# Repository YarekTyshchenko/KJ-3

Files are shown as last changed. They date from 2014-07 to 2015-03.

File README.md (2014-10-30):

KJ-3
====
Programming ATMega328 using an Arduino Micro
--------------------------------------------

All tutorials around programming ATMegas seem to revolve around removing the MCU from
an Arduino Uno and flashing it using normal methods. Since I don't have an Uno, and I
don't plan on getting one, it doesn't fit my needs, I need something that can go into
a breadboard, i've been having a really hard time collecting all the information on
making it work with a Micro and ISCP

So far i've got a few bits of information:

1. Upload ArduinoISP to your Mega, changing the SS definition to pin 10.
1. Modify boards.txt to include your breadboard configuration, or use Arduino Due 328
1. Add ArduinoISP as Micro definition to programmers.txt, found online somehwere
1. Compile and burn the chip with Shift+Ctrl-U (Shift click upload) to use the programmer...

This results in the code running on your new breadboarded MCU!

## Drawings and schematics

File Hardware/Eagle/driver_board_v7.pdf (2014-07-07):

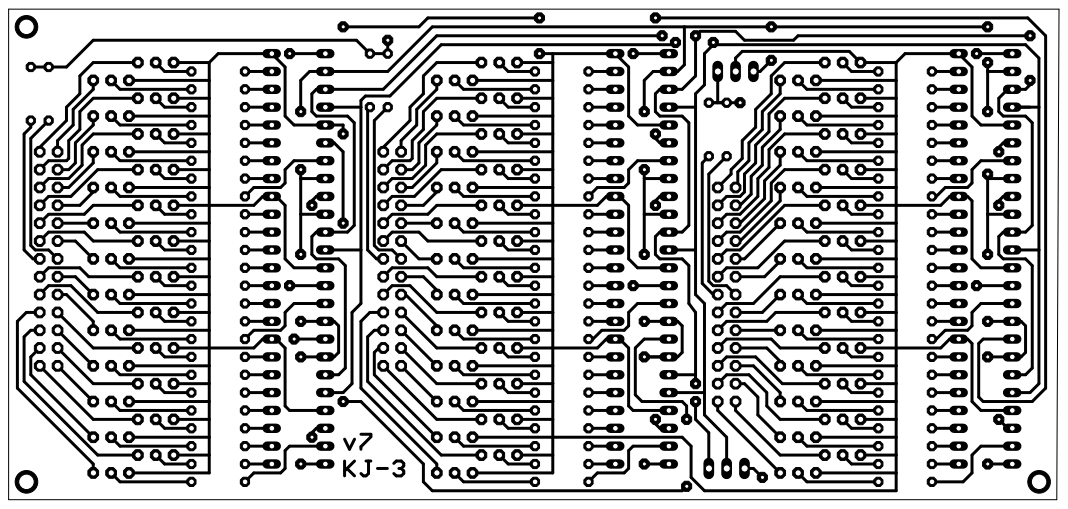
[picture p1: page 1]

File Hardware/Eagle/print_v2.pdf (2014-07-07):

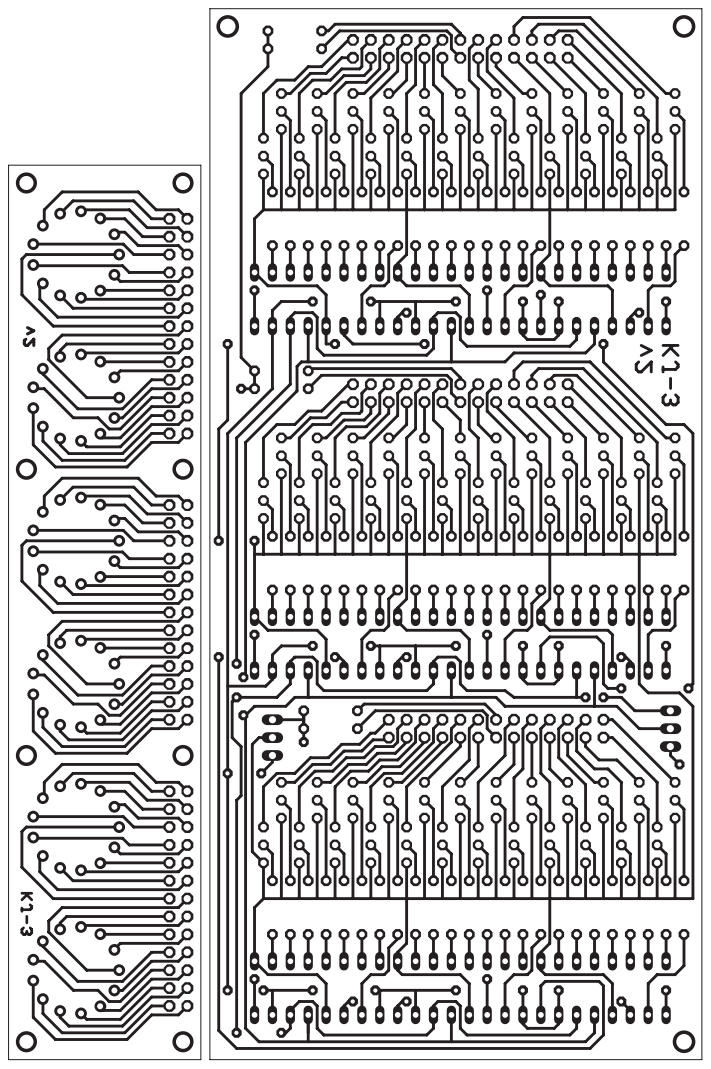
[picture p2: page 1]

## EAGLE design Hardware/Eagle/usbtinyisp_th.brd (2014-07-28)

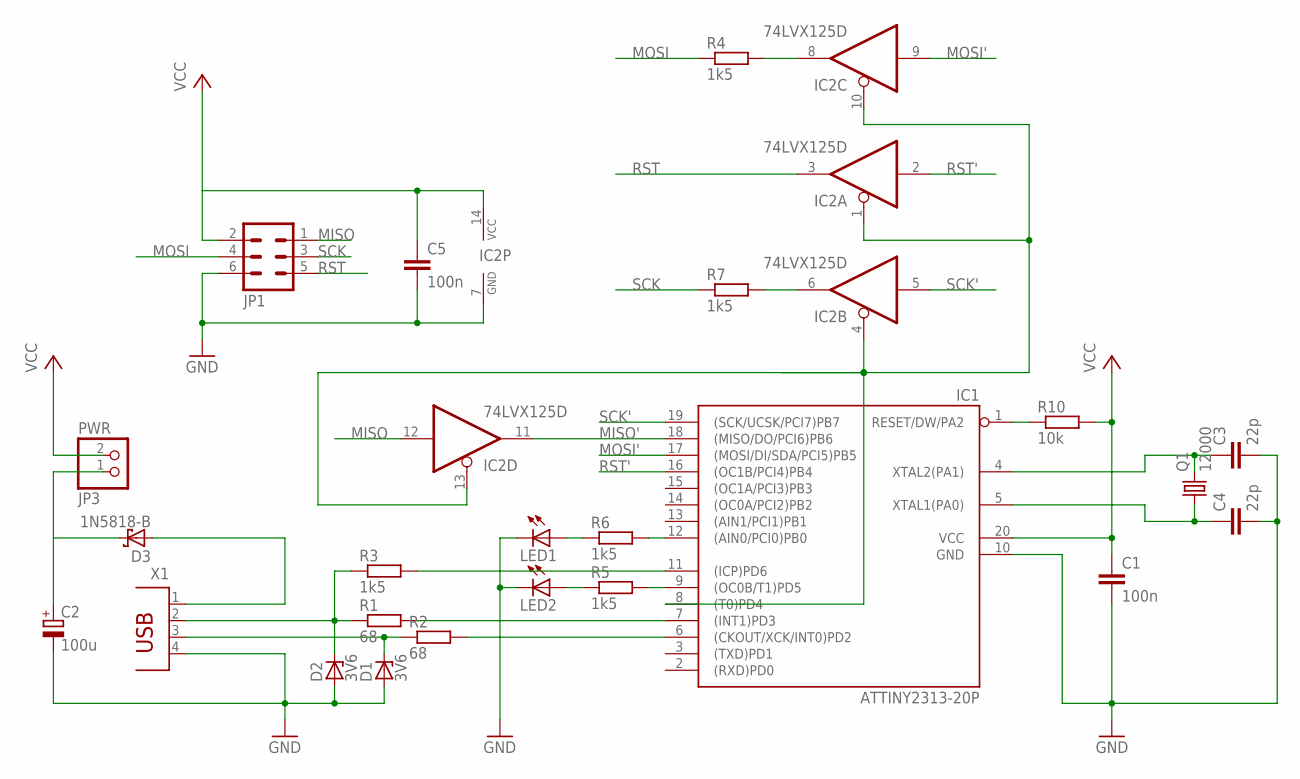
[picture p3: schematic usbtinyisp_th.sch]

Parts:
C1, C5: 100n; C025-025X050
C2: 100u; E2,5-6
C3, C4: 22p; C025-025X050
D1, D2: 3V6; DO35Z10
D3: 1N5818-B; DO41-7.6
IC1: ATTINY2313-20P; DIL20
IC2: 74LVX125D; DIL14
JP1: MA03-2
JP3: PWR; 1X02
LED1, LED2: LED5MM
Q1: 12000; HC49U-V
R1, R2: 68; 0204/7
R3, R4, R5, R6, R7: 1k5; 0204/7
R10: 10k; 0204/7
X1: PN61729

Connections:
GND: C1.2, C2.-, C3.2, C4.2, C5.2, D1.A, D2.A, IC1.10 (GND), IC2.7 (GND), JP1.6, LED1.K (C), LED2.K (C), X1.4
MISO: IC2.12 (I), JP1.1
MISO': IC1.18 ((MISO/DO/PCI6)PB6), IC2.11 (O)
MOSI: JP1.4, R4.1
MOSI': IC1.17 ((MOSI/DI/SDA/PCI5)PB5), IC2.9 (I)
unnamed: D2.C, R1.1, R3.1, X1.2
unnamed: D1.C, R2.1, X1.3
unnamed: IC1.7 ((INT1)PD3), R1.2
unnamed: C2.+, D3.C, JP3.1
unnamed: LED1.A, R6.1
unnamed: IC1.6 ((CKOUT/XCK/INT0)PD2), R2.2
unnamed: IC1.12 ((AIN0/PCI0)PB0), R6.2
unnamed: IC1.1 (RESET/DW/PA2), R10.1
unnamed: IC1.9 ((OC0B/T1)PD5), R5.2
unnamed: LED2.A, R5.1
unnamed: IC2.6 (O), R7.2
unnamed: IC2.8 (O), R4.2
unnamed: IC1.8 ((T0)PD4), IC2.1 (OE), IC2.4 (OE), IC2.10 (OE), IC2.13 (OE)
unnamed: IC1.11 ((ICP)PD6), R3.2
RST: IC2.3 (O), JP1.5
RST': IC1.16 ((OC1B/PCI4)PB4), IC2.2 (I)
SCK: JP1.3, R7.1
SCK': IC1.19 ((SCK/UCSK/PCI7)PB7), IC2.5 (I)
VBUS: D3.A, X1.1
VCC: C1.1, C5.1, IC1.20 (VCC), IC2.14 (VCC), JP1.2, JP3.2, R10.2
XTAL1: C4.1, IC1.5 (XTAL1(PA0)), Q1.1
XTAL2: C3.1, IC1.4 (XTAL2(PA1)), Q1.2

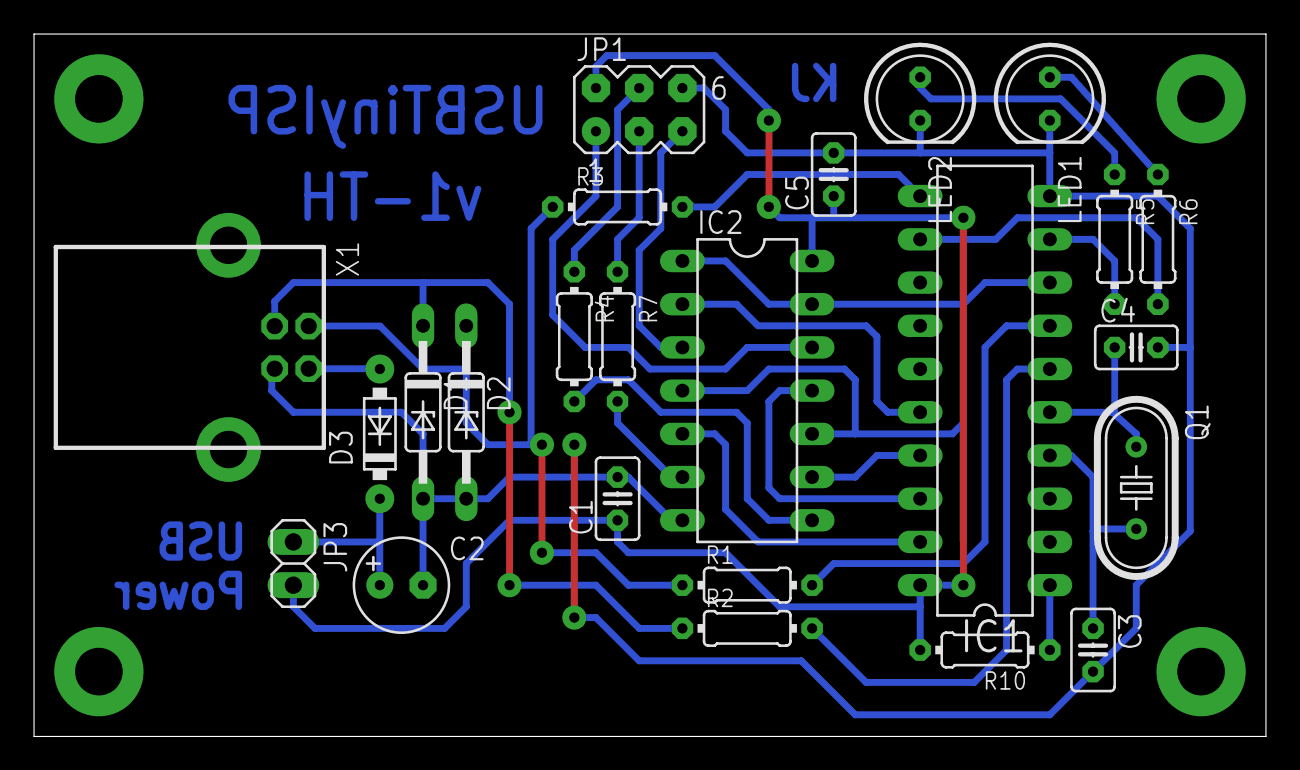
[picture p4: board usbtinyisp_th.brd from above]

Board: 2 copper layers, 72.4 x 41.3 mm, 24 parts (0 on the bottom side), 27 nets.

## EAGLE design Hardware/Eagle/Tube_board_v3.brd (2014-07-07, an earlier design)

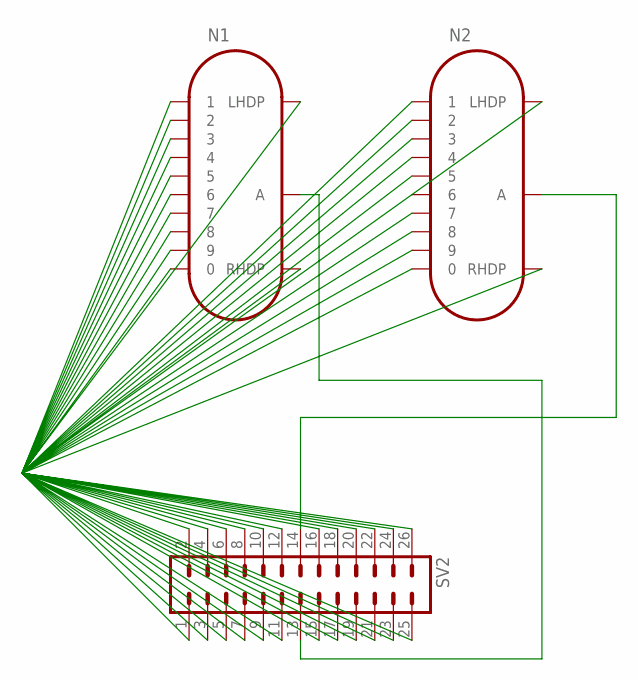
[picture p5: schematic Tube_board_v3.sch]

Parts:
N1, N2: IN-14
SV2: MA13-2

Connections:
unnamed: N1.A, SV2.13
unnamed: N2.A, SV2.14
unnamed: N1.0, N1.1, N1.2, N1.3, N1.4, N1.5, N1.6, N1.7, N1.8, N1.9, N1.LHDP, N1.RHDP, N2.0, N2.1, N2.2, N2.3, N2.4, N2.5, N2.6, N2.7, N2.8, N2.9, N2.LHDP, N2.RHDP, SV2.1, SV2.2, SV2.3, SV2.4, SV2.5, SV2.6, SV2.7, SV2.8, SV2.9, SV2.10, SV2.11, SV2.12, SV2.15, SV2.16, SV2.17, SV2.18, SV2.19, SV2.20, SV2.21, SV2.22, SV2.23, SV2.24, SV2.25, SV2.26

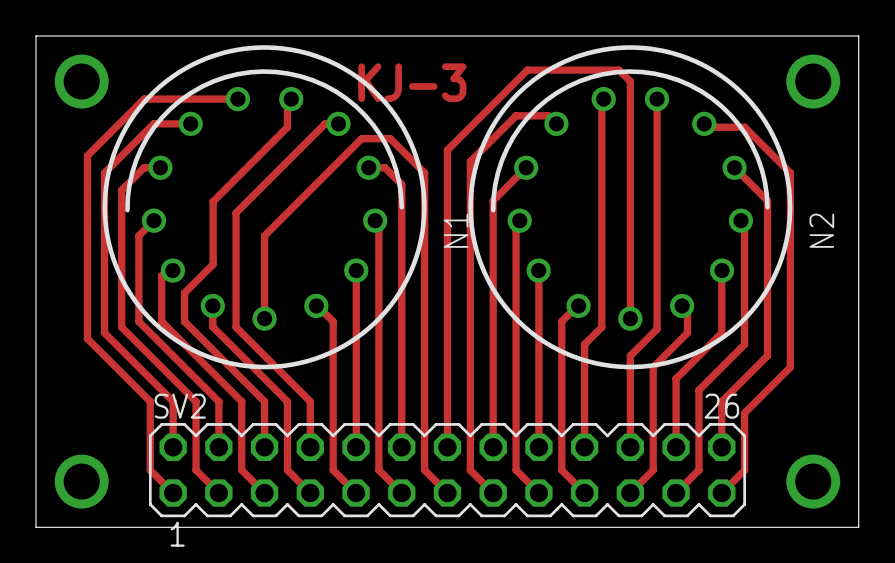
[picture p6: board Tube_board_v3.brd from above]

Board: 2 copper layers, 45.7 x 27.3 mm, 3 parts (0 on the bottom side), 3 nets.

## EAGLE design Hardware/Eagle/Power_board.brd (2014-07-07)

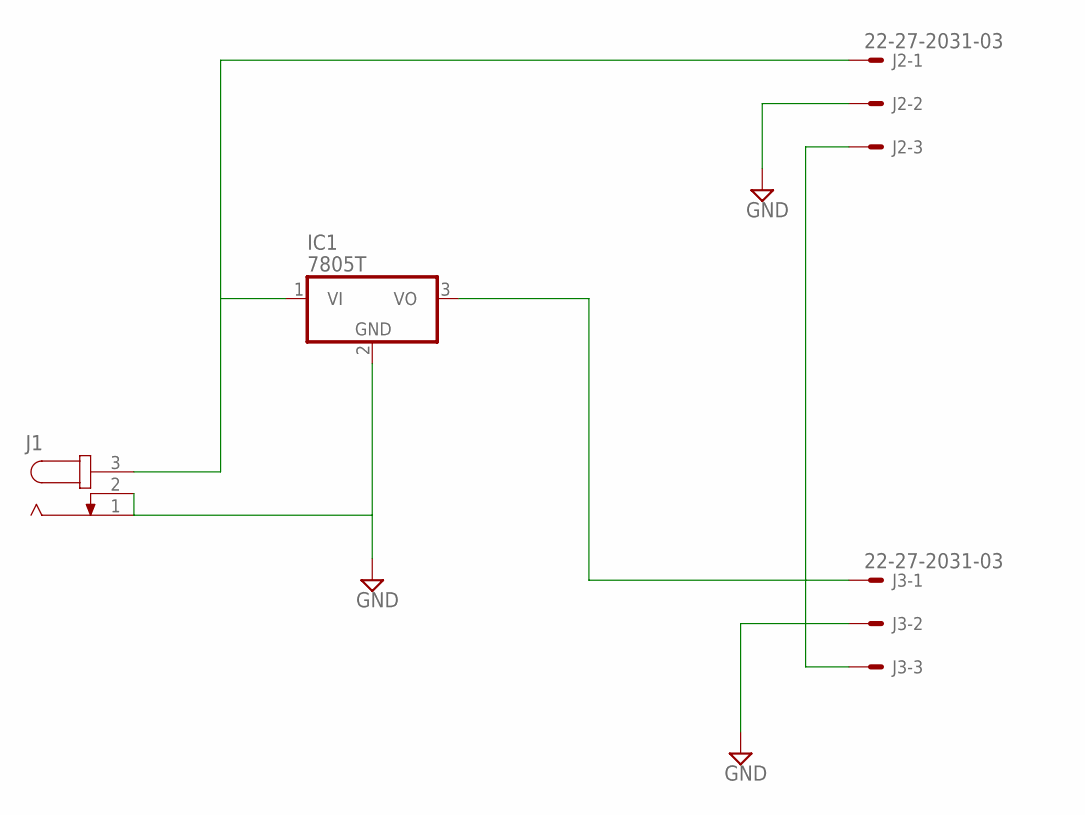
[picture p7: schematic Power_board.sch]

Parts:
IC1: 7805T; TO220H
J1: JACK-PLUG0; SPC4077
J2, J3: 22-27-2031-03; 6410-03

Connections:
GND: IC1.2 (GND), J1.1, J1.2, J2.2, J3.2
unnamed: IC1.1 (VI), J1.3, J2.1
unnamed: J2.3, J3.3
unnamed: IC1.3 (VO), J3.1

Board: 2 copper layers, 4 parts (0 on the bottom side), 4 nets, no tracks yet.

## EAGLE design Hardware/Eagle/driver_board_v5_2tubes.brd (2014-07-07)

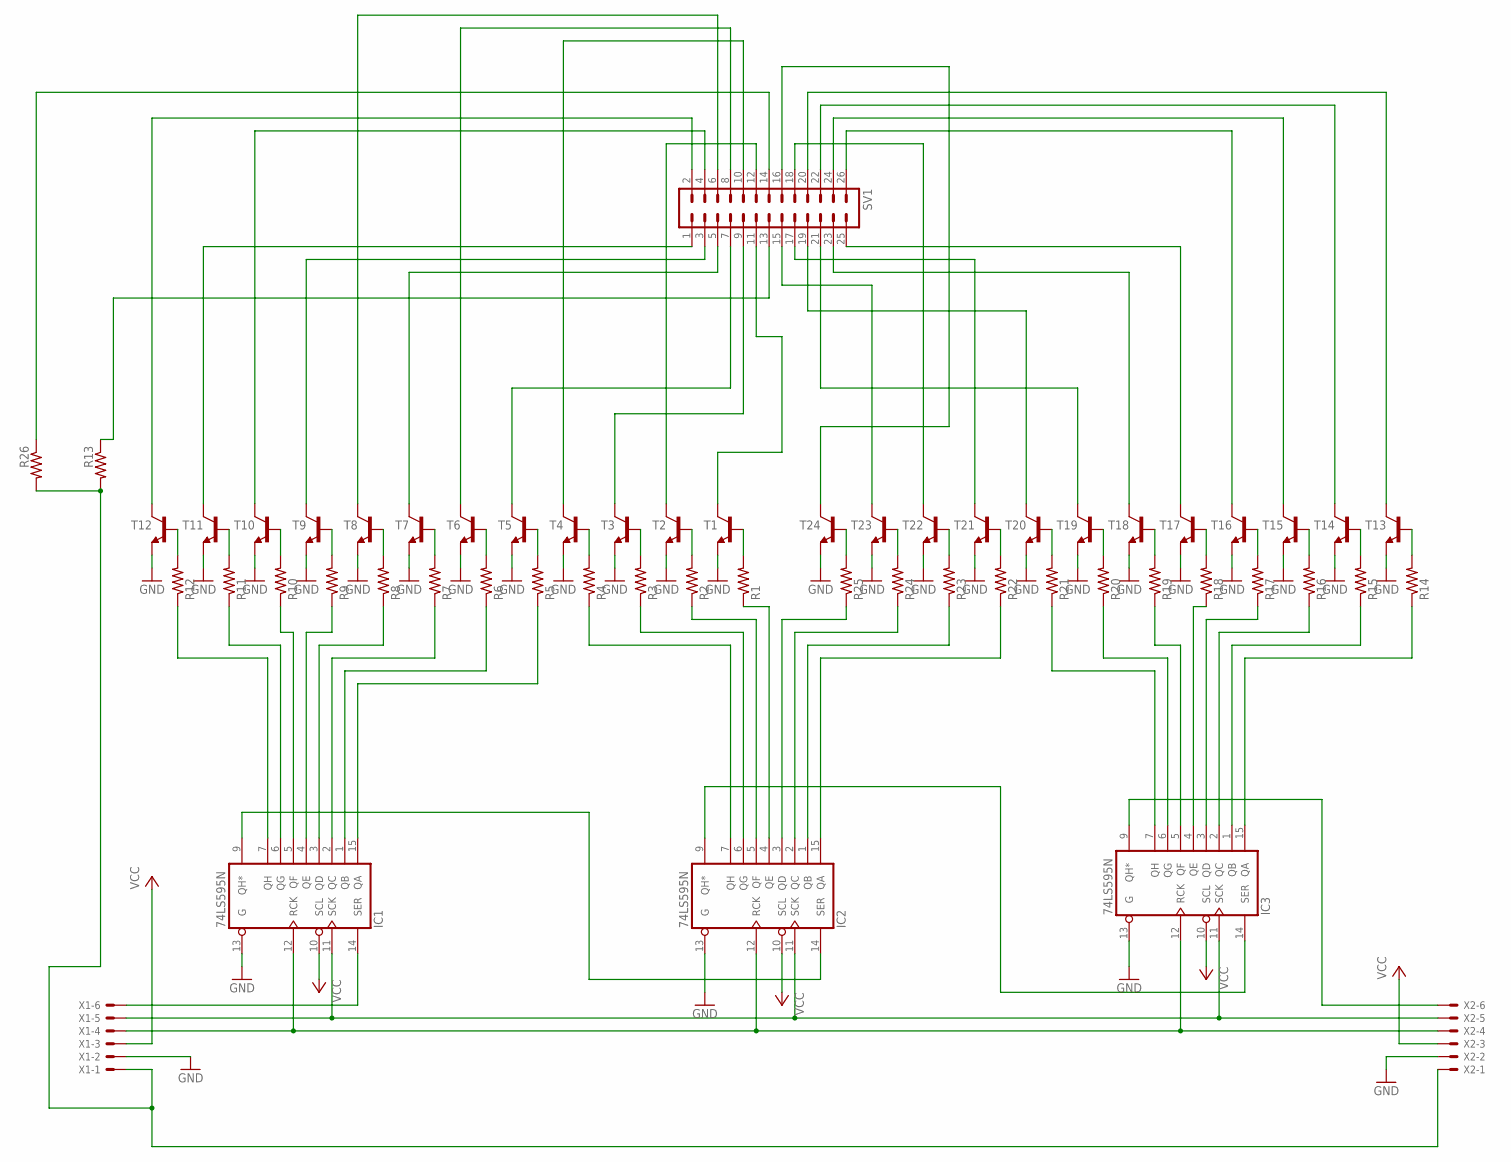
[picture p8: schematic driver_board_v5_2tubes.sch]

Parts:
IC1, IC2, IC3: 74LS595N; DIL16
R1, R2, R3, R4, R5, R6, R7, R8, R9, R10, R11, R12, R13, R14, R15, R16, R17, R18, R19, R20, R21, R22, R23, R24, R25, R26: R-US_0204/7; 0204/7
SV1: MA13-2
T1, T2, T3, T4, T5, T6, T7, T8, T9, T10, T11, T12, T13, T14, T15, T16, T17, T18, T19, T20, T21, T22, T23, T24: 29-NPN-TO92-EBC; TO92-EBC
X1, X2: 22-23-2061

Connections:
GND: IC1.8 (GND), IC1.13 (G), IC2.8 (GND), IC2.13 (G), IC3.8 (GND), IC3.13 (G), T1.E, T2.E, T3.E, T4.E, T5.E, T6.E, T7.E, T8.E, T9.E, T10.E, T11.E, T12.E, T13.E, T14.E, T15.E, T16.E, T17.E, T18.E, T19.E, T20.E, T21.E, T22.E, T23.E, T24.E, X1.2, X2.2
unnamed: R12.2, T12.B
unnamed: R11.2, T11.B
unnamed: R10.2, T10.B
unnamed: R9.2, T9.B
unnamed: R8.2, T8.B
unnamed: R7.2, T7.B
unnamed: R6.2, T6.B
unnamed: R5.2, T5.B
unnamed: R4.2, T4.B
unnamed: R3.2, T3.B
unnamed: R2.2, T2.B
unnamed: R1.2, T1.B
unnamed: SV1.11, T1.C
unnamed: SV1.3, T9.C
unnamed: SV1.6, T8.C
unnamed: SV1.5, T7.C
unnamed: SV1.12, T2.C
unnamed: SV1.9, T3.C
unnamed: SV1.8, T6.C
unnamed: SV1.7, T5.C
unnamed: SV1.10, T4.C
unnamed: R26.1, SV1.14
unnamed: R25.2, T24.B
unnamed: R24.2, T23.B
unnamed: R23.2, T22.B
unnamed: R22.2, T21.B
unnamed: R21.2, T20.B
unnamed: R20.2, T19.B
unnamed: R19.2, T18.B
unnamed: R18.2, T17.B
unnamed: R17.2, T16.B
unnamed: R16.2, T15.B
unnamed: R15.2, T14.B
unnamed: R14.2, T13.B
unnamed: SV1.16, T24.C
unnamed: SV1.15, T23.C
unnamed: SV1.18, T22.C
unnamed: SV1.17, T21.C
unnamed: SV1.19, T20.C
unnamed: SV1.21, T19.C
unnamed: SV1.20, T13.C
unnamed: SV1.22, T14.C
unnamed: SV1.24, T15.C
unnamed: SV1.23, T18.C
unnamed: SV1.25, T17.C
unnamed: SV1.26, T16.C
unnamed: R13.2, R26.2, X1.1, X2.1
unnamed: R13.1, SV1.13
unnamed: IC1.9 (QH*), IC2.14 (SER)
unnamed: IC2.9 (QH*), IC3.14 (SER)
unnamed: IC3.9 (QH*), X2.6
unnamed: IC1.14 (SER), X1.6
unnamed: SV1.2, T12.C
unnamed: IC1.11 (SCK), IC2.11 (SCK), IC3.11 (SCK), X1.5, X2.5
unnamed: IC1.12 (RCK), IC2.12 (RCK), IC3.12 (RCK), X1.4, X2.4
unnamed: SV1.1, T11.C
unnamed: SV1.4, T10.C
unnamed: IC1.7 (QH), R12.1
unnamed: IC1.6 (QG), R11.1
unnamed: IC1.5 (QF), R10.1
unnamed: IC1.4 (QE), R9.1
unnamed: IC1.3 (QD), R8.1
unnamed: IC1.2 (QC), R7.1
unnamed: IC1.1 (QB), R6.1
unnamed: IC1.15 (QA), R5.1
unnamed: IC2.7 (QH), R4.1
unnamed: IC2.6 (QG), R3.1
unnamed: IC2.5 (QF), R2.1
unnamed: IC2.4 (QE), R1.1
unnamed: IC2.3 (QD), R25.1
unnamed: IC2.2 (QC), R24.1
unnamed: IC2.1 (QB), R23.1
unnamed: IC2.15 (QA), R22.1
unnamed: IC3.7 (QH), R21.1
unnamed: IC3.6 (QG), R20.1
unnamed: IC3.5 (QF), R19.1
unnamed: IC3.4 (QE), R18.1
unnamed: IC3.3 (QD), R17.1
unnamed: IC3.2 (QC), R16.1
unnamed: IC3.1 (QB), R15.1
unnamed: IC3.15 (QA), R14.1
VCC: IC1.10 (SCL), IC1.16 (VCC), IC2.10 (SCL), IC2.16 (VCC), IC3.10 (SCL), IC3.16 (VCC), X1.3, X2.3

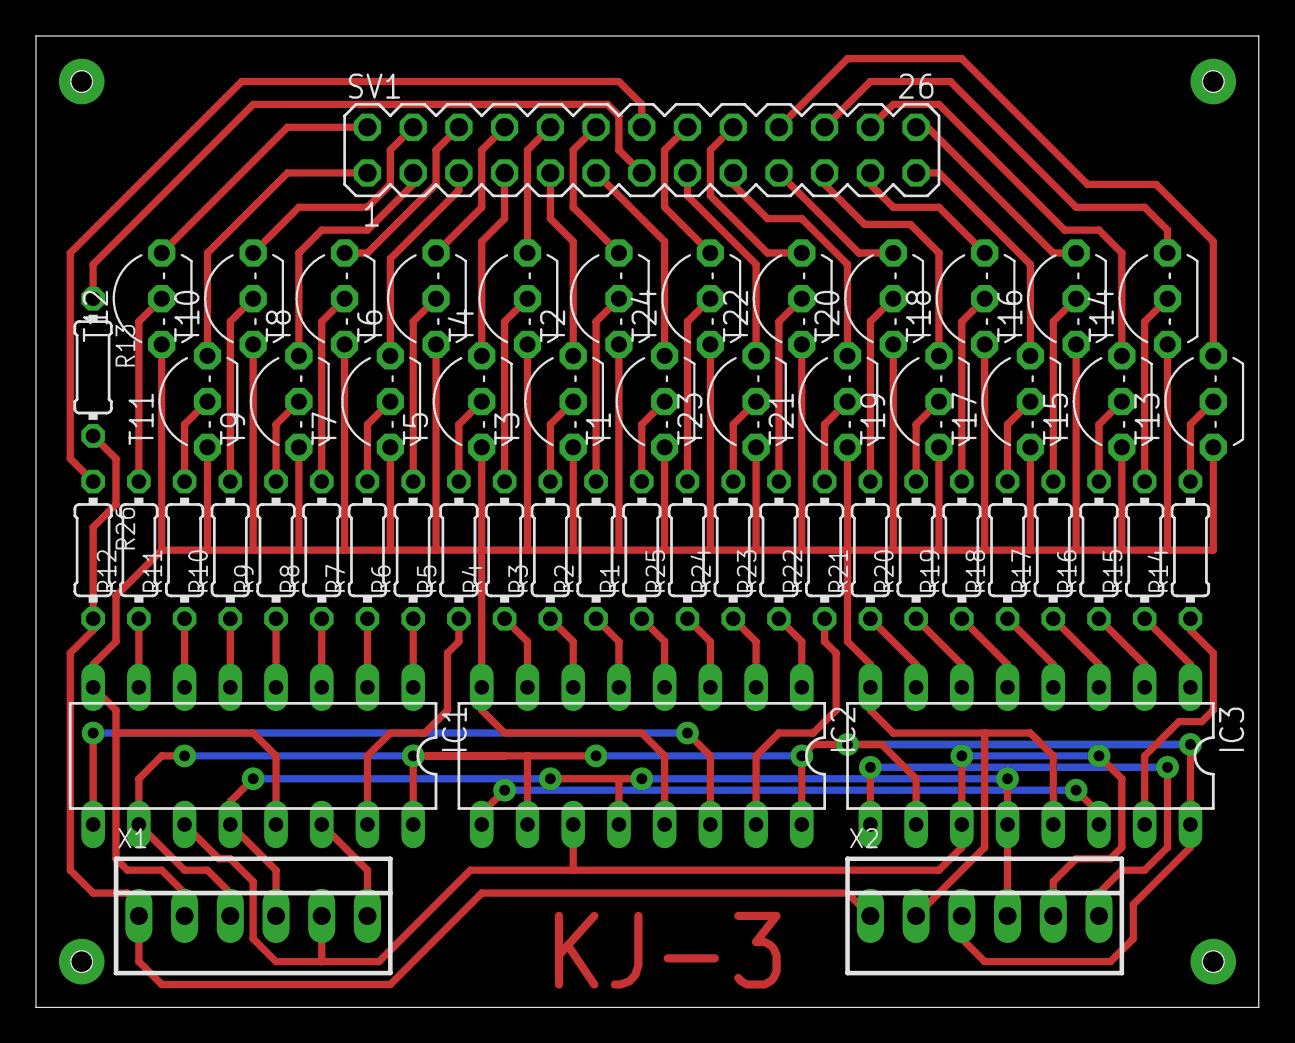
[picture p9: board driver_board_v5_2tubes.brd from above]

Board: 2 copper layers, 67.9 x 54.0 mm, 56 parts (0 on the bottom side), 83 nets.

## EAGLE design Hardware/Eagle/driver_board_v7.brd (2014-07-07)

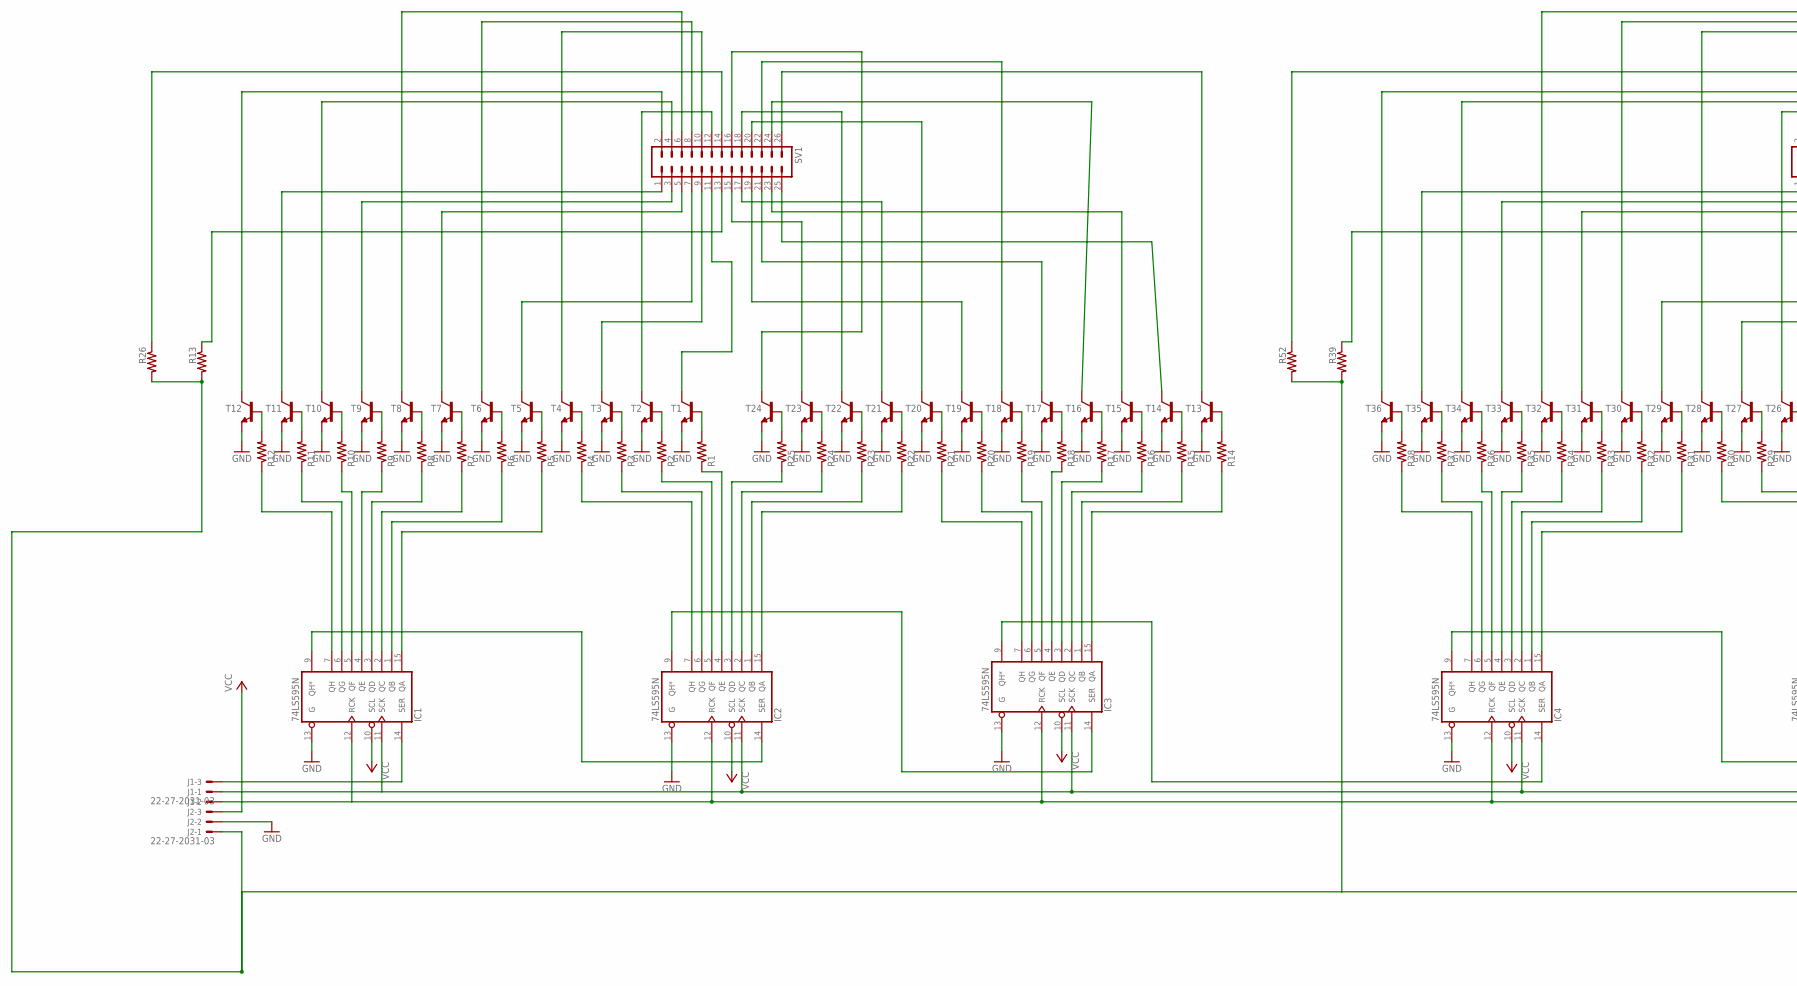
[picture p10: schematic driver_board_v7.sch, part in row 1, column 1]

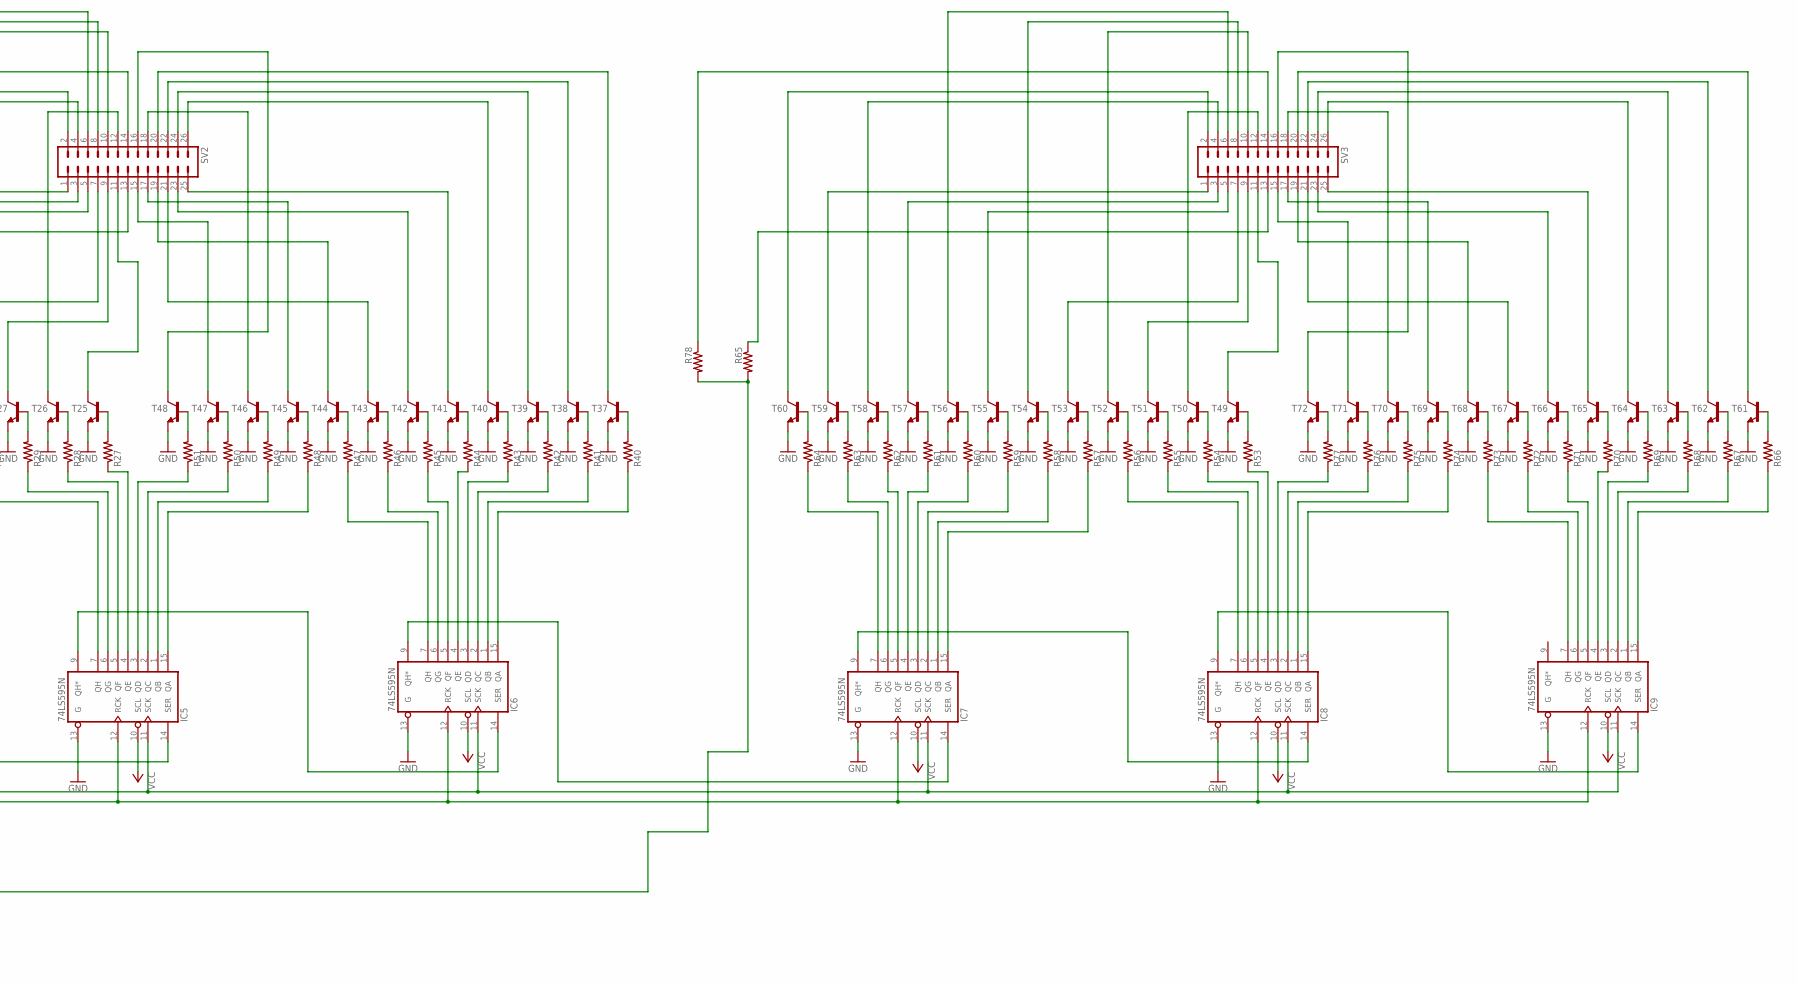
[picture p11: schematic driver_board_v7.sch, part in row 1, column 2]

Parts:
IC1, IC2, IC3, IC4, IC5, IC6, IC7, IC8, IC9: 74LS595N; DIL16
J1, J2: 22-27-2031-03; 6410-03
R1, R2, R3, R4, R5, R6, R7, R8, R9, R10, R11, R12, R13, R14, R15, R16, R17, R18, R19, R20, R21, R22, R23, R24, R25, R26, R27, R28, R29, R30, R31, R32, R33, R34, R35, R36, R37, R38, R39, R40, R41, R42, R43, R44, R45, R46, R47, R48, R49, R50, R51, R52, R53, R54, R55, R56, R57, R58, R59, R60, R61, R62, R63, R64, R65, R66, R67, R68, R69, R70, R71, R72, R73, R74, R75, R76, R77, R78: R-US_0204/7; 0204/7
SV1, SV2, SV3: MA13-2
T1, T2, T3, T4, T5, T6, T7, T8, T9, T10, T11, T12, T13, T14, T15, T16, T17, T18, T19, T20, T21, T22, T23, T24, T25, T26, T27, T28, T29, T30, T31, T32, T33, T34, T35, T36, T37, T38, T39, T40, T41, T42, T43, T44, T45, T46, T47, T48, T49, T50, T51, T52, T53, T54, T55, T56, T57, T58, T59, T60, T61, T62, T63, T64, T65, T66, T67, T68, T69, T70, T71, T72: 29-NPN-TO92-EBC; TO92-EBC

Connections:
GND: IC1.8 (GND), IC1.13 (G), IC2.8 (GND), IC2.13 (G), IC3.8 (GND), IC3.13 (G), IC4.8 (GND), IC4.13 (G), IC5.8 (GND), IC5.13 (G), IC6.8 (GND), IC6.13 (G), IC7.8 (GND), IC7.13 (G), IC8.8 (GND), IC8.13 (G), IC9.8 (GND), IC9.13 (G), J2.2, T1.E, T2.E, T3.E, T4.E, T5.E, T6.E, T7.E, T8.E, T9.E, T10.E, T11.E, T12.E, T13.E, T14.E, T15.E, T16.E, T17.E, T18.E, T19.E, T20.E, T21.E, T22.E, T23.E, T24.E, T25.E, T26.E, T27.E, T28.E, T29.E, T30.E, T31.E, T32.E, T33.E, T34.E, T35.E, T36.E, T37.E, T38.E, T39.E, T40.E, T41.E, T42.E, T43.E, T44.E, T45.E, T46.E, T47.E, T48.E, T49.E, T50.E, T51.E, T52.E, T53.E, T54.E, T55.E, T56.E, T57.E, T58.E, T59.E, T60.E, T61.E, T62.E, T63.E, T64.E, T65.E, T66.E, T67.E, T68.E, T69.E, T70.E, T71.E, T72.E
HV: J2.1, R13.2, R26.2, R39.2, R52.2, R65.2, R78.2
unnamed: R12.2, T12.B
unnamed: R11.2, T11.B
unnamed: R10.2, T10.B
unnamed: R9.2, T9.B
unnamed: R8.2, T8.B
unnamed: R7.2, T7.B
unnamed: R6.2, T6.B
unnamed: R5.2, T5.B
unnamed: R4.2, T4.B
unnamed: R3.2, T3.B
unnamed: R2.2, T2.B
unnamed: R1.2, T1.B
unnamed: SV1.11, T1.C
unnamed: R38.2, T36.B
unnamed: R37.2, T35.B
unnamed: SV1.3, T9.C
unnamed: SV1.6, T8.C
unnamed: SV1.5, T7.C
unnamed: R36.2, T34.B
unnamed: SV1.12, T2.C
unnamed: SV1.9, T3.C
unnamed: SV1.8, T6.C
unnamed: SV1.7, T5.C
unnamed: SV1.10, T4.C
unnamed: R26.1, SV1.14
unnamed: R25.2, T24.B
unnamed: R24.2, T23.B
unnamed: R23.2, T22.B
unnamed: R22.2, T21.B
unnamed: R21.2, T20.B
unnamed: R20.2, T19.B
unnamed: R19.2, T18.B
unnamed: R18.2, T17.B
unnamed: R17.2, T16.B
unnamed: R16.2, T15.B
unnamed: R15.2, T14.B
unnamed: R14.2, T13.B
unnamed: SV1.16, T24.C
unnamed: SV1.15, T23.C
unnamed: SV1.18, T22.C
unnamed: SV1.17, T21.C
unnamed: SV1.20, T20.C
unnamed: SV1.19, T19.C
unnamed: SV1.26, T13.C
unnamed: SV1.25, T14.C
unnamed: SV1.23, T15.C
unnamed: SV1.22, T18.C
unnamed: SV1.21, T17.C
unnamed: SV1.24, T16.C
unnamed: R13.1, SV1.13
unnamed: IC1.9 (QH*), IC2.14 (SER)
unnamed: IC2.9 (QH*), IC3.14 (SER)
unnamed: IC3.9 (QH*), IC4.14 (SER)
unnamed: R35.2, T33.B
unnamed: SV1.2, T12.C
unnamed: SV1.1, T11.C
unnamed: SV1.4, T10.C
unnamed: R34.2, T32.B
unnamed: R33.2, T31.B
unnamed: R32.2, T30.B
unnamed: R31.2, T29.B
unnamed: R30.2, T28.B
unnamed: R29.2, T27.B
unnamed: R28.2, T26.B
unnamed: R27.2, T25.B
unnamed: SV2.3, T33.C
unnamed: SV2.6, T32.C
unnamed: SV2.5, T31.C
unnamed: SV2.12, T26.C
unnamed: SV2.9, T27.C
unnamed: IC1.7 (QH), R12.1
unnamed: IC1.6 (QG), R11.1
unnamed: IC1.5 (QF), R10.1
unnamed: IC1.4 (QE), R9.1
unnamed: IC1.3 (QD), R8.1
unnamed: IC1.2 (QC), R7.1
unnamed: IC1.1 (QB), R6.1
unnamed: IC1.15 (QA), R5.1
unnamed: SV2.8, T30.C
unnamed: IC2.7 (QH), R4.1
unnamed: IC2.6 (QG), R3.1
unnamed: IC2.5 (QF), R2.1
unnamed: IC2.4 (QE), R1.1
unnamed: IC2.3 (QD), R25.1
unnamed: IC2.2 (QC), R24.1
unnamed: IC2.1 (QB), R23.1
unnamed: IC2.15 (QA), R22.1
unnamed: IC3.7 (QH), R21.1
unnamed: IC3.6 (QG), R20.1
unnamed: IC3.5 (QF), R19.1
unnamed: IC3.4 (QE), R18.1
unnamed: IC3.3 (QD), R17.1
unnamed: IC3.2 (QC), R16.1
unnamed: IC3.1 (QB), R15.1
unnamed: IC3.15 (QA), R14.1
unnamed: SV2.7, T29.C
unnamed: SV2.10, T28.C
unnamed: R51.2, T48.B
unnamed: R50.2, T47.B
unnamed: R49.2, T46.B
unnamed: R48.2, T45.B
unnamed: R47.2, T44.B
unnamed: R46.2, T43.B
unnamed: R45.2, T42.B
unnamed: R44.2, T41.B
unnamed: R43.2, T40.B
unnamed: R42.2, T39.B
unnamed: R41.2, T38.B
unnamed: R40.2, T37.B
unnamed: SV2.16, T48.C
unnamed: SV2.15, T47.C
unnamed: SV2.18, T46.C
unnamed: SV2.17, T45.C
unnamed: SV2.19, T44.C
unnamed: SV2.21, T43.C
unnamed: SV2.20, T37.C
unnamed: SV2.22, T38.C
unnamed: SV2.24, T39.C
unnamed: SV2.23, T42.C
unnamed: SV2.25, T41.C
unnamed: SV2.26, T40.C
unnamed: IC4.7 (QH), R38.1
unnamed: IC4.6 (QG), R37.1
unnamed: IC4.5 (QF), R36.1
unnamed: IC4.4 (QE), R35.1
unnamed: IC4.3 (QD), R34.1
unnamed: IC4.2 (QC), R33.1
unnamed: IC4.1 (QB), R32.1
unnamed: IC4.15 (QA), R31.1
unnamed: IC5.7 (QH), R30.1
unnamed: IC5.6 (QG), R29.1
unnamed: IC5.5 (QF), R28.1
unnamed: IC5.4 (QE), R27.1
unnamed: IC5.3 (QD), R51.1
unnamed: IC5.2 (QC), R50.1
unnamed: IC5.1 (QB), R49.1
unnamed: IC5.15 (QA), R48.1
unnamed: IC6.7 (QH), R47.1
unnamed: IC6.6 (QG), R46.1
unnamed: IC6.5 (QF), R45.1
unnamed: IC6.4 (QE), R44.1
unnamed: IC6.3 (QD), R43.1
unnamed: IC6.2 (QC), R42.1
unnamed: IC6.1 (QB), R41.1
unnamed: IC6.15 (QA), R40.1
unnamed: IC4.9 (QH*), IC5.14 (SER)
unnamed: IC5.9 (QH*), IC6.14 (SER)
unnamed: IC6.9 (QH*), IC7.14 (SER)
unnamed: SV2.11, T25.C
unnamed: R52.1, SV2.14
unnamed: R39.1, SV2.13
unnamed: SV2.2, T36.C
unnamed: SV2.1, T35.C
unnamed: SV2.4, T34.C
unnamed: R64.2, T60.B
unnamed: R63.2, T59.B
unnamed: R62.2, T58.B
unnamed: R61.2, T57.B
unnamed: R60.2, T56.B
unnamed: R59.2, T55.B
unnamed: R58.2, T54.B
unnamed: R57.2, T53.B
unnamed: R56.2, T52.B
unnamed: R55.2, T51.B
unnamed: R54.2, T50.B
unnamed: R53.2, T49.B
unnamed: SV3.3, T57.C
unnamed: SV3.6, T56.C
unnamed: SV3.5, T55.C
unnamed: SV3.12, T50.C
unnamed: SV3.9, T51.C
unnamed: SV3.8, T54.C
unnamed: SV3.7, T53.C
unnamed: SV3.10, T52.C
unnamed: R77.2, T72.B
unnamed: R76.2, T71.B
unnamed: R75.2, T70.B
unnamed: R74.2, T69.B
unnamed: R73.2, T68.B
unnamed: R72.2, T67.B
unnamed: R71.2, T66.B
unnamed: R70.2, T65.B
unnamed: R69.2, T64.B
unnamed: R68.2, T63.B
unnamed: R67.2, T62.B
unnamed: R66.2, T61.B
unnamed: SV3.16, T72.C
unnamed: SV3.15, T71.C
unnamed: SV3.18, T70.C
unnamed: SV3.17, T69.C
unnamed: SV3.19, T68.C
unnamed: SV3.21, T67.C
unnamed: SV3.20, T61.C
unnamed: SV3.22, T62.C
unnamed: SV3.24, T63.C
unnamed: SV3.23, T66.C
unnamed: SV3.25, T65.C
unnamed: SV3.26, T64.C
unnamed: IC7.7 (QH), R64.1
unnamed: IC7.6 (QG), R63.1
unnamed: IC7.5 (QF), R62.1
unnamed: IC7.4 (QE), R61.1
unnamed: IC7.3 (QD), R60.1
unnamed: IC7.2 (QC), R59.1
unnamed: IC7.1 (QB), R58.1
unnamed: IC7.15 (QA), R57.1
unnamed: IC8.7 (QH), R56.1
unnamed: IC8.6 (QG), R55.1
unnamed: IC8.5 (QF), R54.1
unnamed: IC8.4 (QE), R53.1
unnamed: IC8.3 (QD), R77.1
unnamed: IC8.2 (QC), R76.1
unnamed: IC8.1 (QB), R75.1
unnamed: IC8.15 (QA), R74.1
unnamed: IC9.7 (QH), R73.1
unnamed: IC9.6 (QG), R72.1
unnamed: IC9.5 (QF), R71.1
unnamed: IC9.4 (QE), R70.1
unnamed: IC9.3 (QD), R69.1
unnamed: IC9.2 (QC), R68.1
unnamed: IC9.1 (QB), R67.1
unnamed: IC9.15 (QA), R66.1
unnamed: IC7.9 (QH*), IC8.14 (SER)
unnamed: IC8.9 (QH*), IC9.14 (SER)
unnamed: SV3.11, T49.C
unnamed: R78.1, SV3.14
unnamed: R65.1, SV3.13
unnamed: SV3.2, T60.C
unnamed: SV3.1, T59.C
unnamed: SV3.4, T58.C
RCK: IC1.12 (RCK), IC2.12 (RCK), IC3.12 (RCK), IC4.12 (RCK), IC5.12 (RCK), IC6.12 (RCK), IC7.12 (RCK), IC8.12 (RCK), IC9.12 (RCK), J1.2
SCK: IC1.11 (SCK), IC2.11 (SCK), IC3.11 (SCK), IC4.11 (SCK), IC5.11 (SCK), IC6.11 (SCK), IC7.11 (SCK), IC8.11 (SCK), IC9.11 (SCK), J1.1
SER: IC1.14 (SER), J1.3
VCC: IC1.10 (SCL), IC1.16 (VCC), IC2.10 (SCL), IC2.16 (VCC), IC3.10 (SCL), IC3.16 (VCC), IC4.10 (SCL), IC4.16 (VCC), IC5.10 (SCL), IC5.16 (VCC), IC6.10 (SCL), IC6.16 (VCC), IC7.10 (SCL), IC7.16 (VCC), IC8.10 (SCL), IC8.16 (VCC), IC9.10 (SCL), IC9.16 (VCC), J2.3

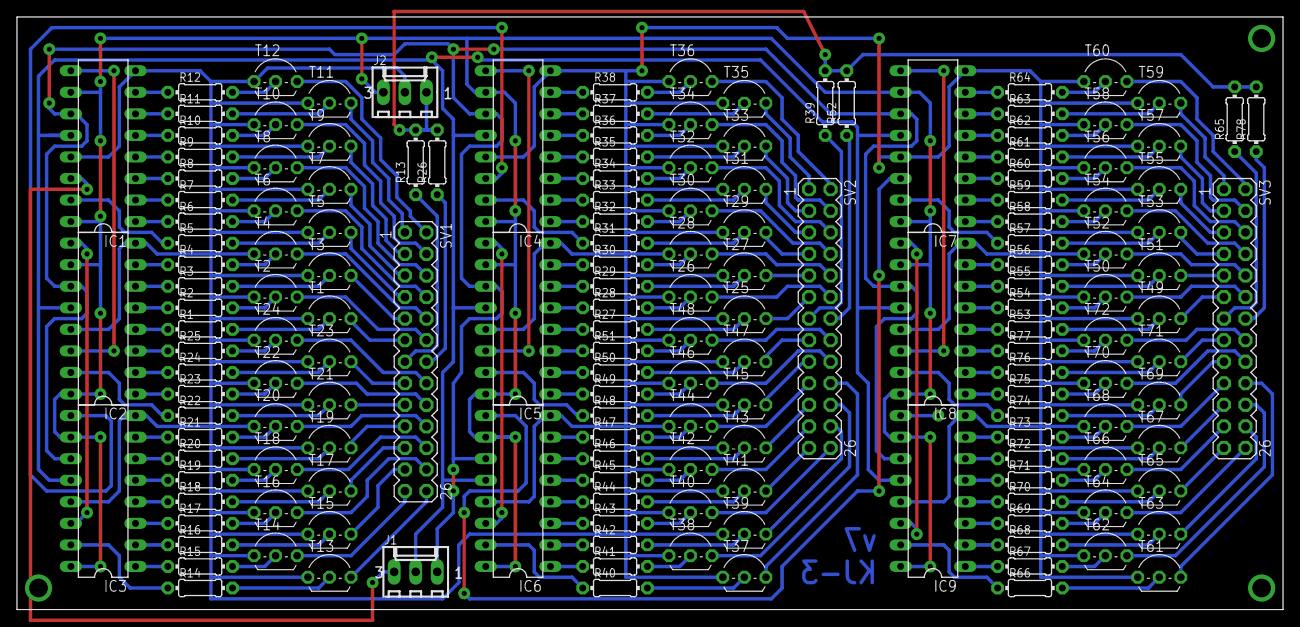
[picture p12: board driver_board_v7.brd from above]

Board: 2 copper layers, 149.2 x 69.8 mm, 164 parts (0 on the bottom side), 236 nets.

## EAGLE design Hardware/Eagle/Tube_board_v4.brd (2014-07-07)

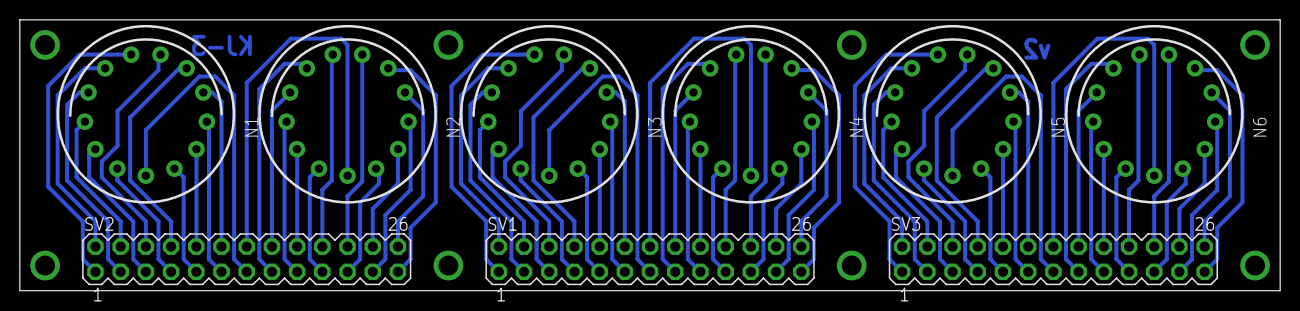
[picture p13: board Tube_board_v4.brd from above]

Board: 2 copper layers, 127.0 x 27.3 mm, 9 parts (0 on the bottom side), 9 nets.

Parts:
N1, N2, N3, N4, N5, N6: IN-14
SV1, SV2, SV3: MA13-2

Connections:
unnamed: N1.A, SV2.13
unnamed: N2.A, SV2.14
unnamed: N1.0, N1.1, N1.2, N1.3, N1.4, N1.5, N1.6, N1.7, N1.8, N1.9, N1.LHDP, N1.RHDP, N2.0, N2.1, N2.2, N2.3, N2.4, N2.5, N2.6, N2.7, N2.8, N2.9, N2.LHDP, N2.RHDP, SV2.1, SV2.2, SV2.3, SV2.4, SV2.5, SV2.6, SV2.7, SV2.8, SV2.9, SV2.10, SV2.11, SV2.12, SV2.15, SV2.16, SV2.17, SV2.18, SV2.19, SV2.20, SV2.21, SV2.22, SV2.23, SV2.24, SV2.25, SV2.26
unnamed: N3.A, SV1.13
unnamed: N4.A, SV1.14
unnamed: N3.0, N3.1, N3.2, N3.3, N3.4, N3.5, N3.6, N3.7, N3.8, N3.9, N3.LHDP, N3.RHDP, N4.0, N4.1, N4.2, N4.3, N4.4, N4.5, N4.6, N4.7, N4.8, N4.9, N4.LHDP, N4.RHDP, SV1.1, SV1.2, SV1.3, SV1.4, SV1.5, SV1.6, SV1.7, SV1.8, SV1.9, SV1.10, SV1.11, SV1.12, SV1.15, SV1.16, SV1.17, SV1.18, SV1.19, SV1.20, SV1.21, SV1.22, SV1.23, SV1.24, SV1.25, SV1.26
unnamed: N5.A, SV3.13
unnamed: N6.A, SV3.14
unnamed: N5.0, N5.1, N5.2, N5.3, N5.4, N5.5, N5.6, N5.7, N5.8, N5.9, N5.LHDP, N5.RHDP, N6.0, N6.1, N6.2, N6.3, N6.4, N6.5, N6.6, N6.7, N6.8, N6.9, N6.LHDP, N6.RHDP, SV3.1, SV3.2, SV3.3, SV3.4, SV3.5, SV3.6, SV3.7, SV3.8, SV3.9, SV3.10, SV3.11, SV3.12, SV3.15, SV3.16, SV3.17, SV3.18, SV3.19, SV3.20, SV3.21, SV3.22, SV3.23, SV3.24, SV3.25, SV3.26

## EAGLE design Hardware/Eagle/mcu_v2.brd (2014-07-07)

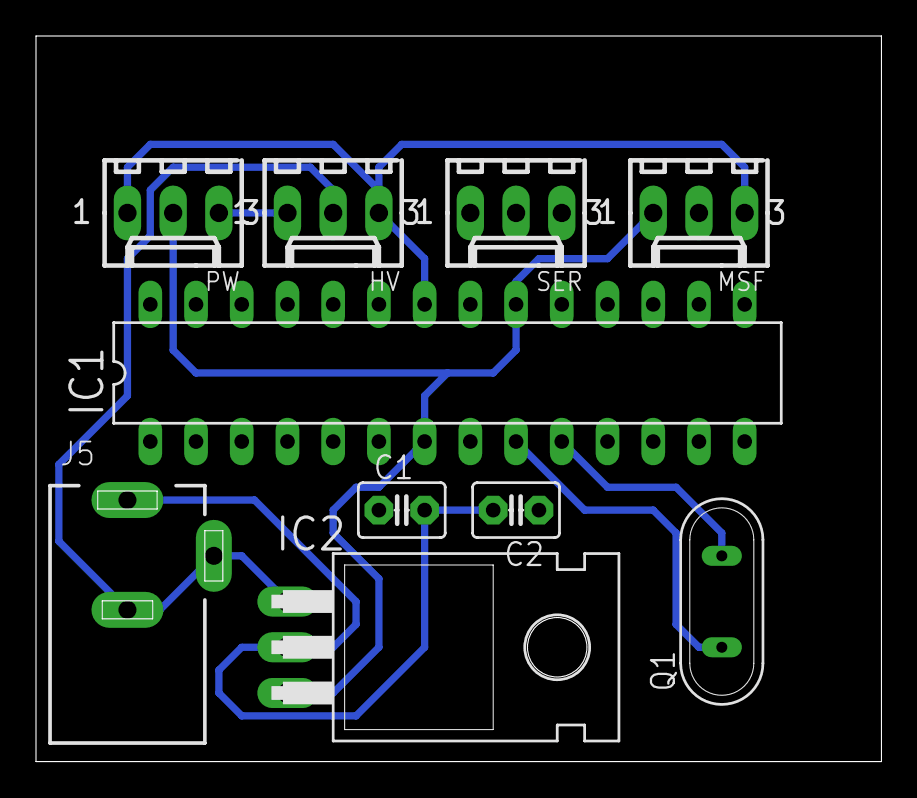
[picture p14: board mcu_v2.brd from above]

Board: 2 copper layers, 47.0 x 40.3 mm, 10 parts (0 on the bottom side), 10 nets.

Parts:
C1, C2: C2.5-3
HV: 22-27-2031-03; 6410-03
IC1: MEGA8-P; DIL28-3
IC2: 7805T; TO220H
J5: DCJ0202
MSF: 22-27-2031-03; 6410-03
PW: 22-27-2031-03; 6410-03
Q1: QS
SER: 22-27-2031-03; 6410-03

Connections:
GND: C1.2, C2.2, HV.3, IC1.8, IC1.22, IC2.2, J5.1, MSF.3, PW.1
unnamed: HV.2, IC2.1, J5.2, J5.3
unnamed: HV.1, PW.3
unnamed: C2.1, IC1.10, Q1.2
unnamed: C1.1, IC1.9, Q1.1
unnamed: IC1.5, MSF.2
unnamed: IC1.23, SER.1
unnamed: IC1.24, SER.2
unnamed: IC1.25, SER.3
VCC: IC1.7, IC1.20, IC2.3, MSF.1, PW.2

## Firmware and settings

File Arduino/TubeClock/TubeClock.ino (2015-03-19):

#include "Tube.h"
#include "NtpClient.h"

// Libraries
#include <EtherCard.h>
#include <Time.h>
#include <Timezone.h>
#include <ArduinoJson.h>

//United Kingdom (London, Belfast)
TimeChangeRule BST = {"BST", Last, Sun, Mar, 1, 60}; //British Summer Time
TimeChangeRule GMT = {"GMT", Last, Sun, Oct, 2, 0};  //Standard Time
Timezone UK(BST, GMT);
TimeChangeRule *tcr;

//Pin connected to ST_CP of 74HC595
int latchPin = 6; //10
//Pin connected to SH_CP of 74HC595
int clockPin = 5; //12
////Pin connected to DS of 74HC595
int dataPin = 7; //11

// Setup the tube display interface
Tube tube(clockPin, dataPin, latchPin);

// @TODO: Add an array of ntp servers
static uint8_t macAddress[6] = { 0x54,0x55,0x58,0x10,0x00,0x25};
NtpClient ntpClient(macAddress);
time_t localTime;

bool inSync = false;
unsigned int frameRate = 0;
uint32_t millisPerSecond = 0L;
uint32_t resetMillis;

int mode = 1; // 1 default
void udpListen(word port, byte ip[4], const char *data, word len) {
    StaticJsonBuffer<200> jsonBuffer;
    JsonObject& root = jsonBuffer.parseObject(const_cast<char*>(data));
    if (!root.success()) {
        return;
    }

    JsonObject& stats = jsonBuffer.createObject();
    populateStats(stats);
    switchMode(root);
    char buffer[256];
    stats.printTo(buffer, sizeof(buffer));
    ntpClient.makeUdpReply(buffer, strlen(buffer), port);
}

unsigned int timer = 30; // Seconds on a timer
void switchMode(JsonObject& root) {
    int commandMode = root["mode"];
    switch (commandMode) {
        case 1: // Reset to default mode
            mode = 1;
            break;
        case 2: // Display of frame rate
            mode = 2;
            break;
        case 3: // Display timer
            mode = 3;
            break;
        case 4: // Increment/decrement timer
            timer += root["timer"].as<int>();
            break;
        //case 5: return 5; // Display time since bootup
        case 6: // Sync now
            inSync = false;
            break;
        case 7: // Disable tubes ready for code push
            mode = 4;
            break;
        case 8: // seconds to next sync
            mode = 5;
            break;
        case 9:
            mode = 6;
            break;
        default: // Default, do nothing
            break;
    }
}

void populateStats(JsonObject& stats) {
    stats["frameRate"] = frameRate;
    stats["timer"] = timer;
    stats["mode"] = mode;
    stats["mps"] = millisPerSecond;
    stats["nowMillis"] = millis() - resetMillis;
}

time_t timerStart = NULL;
uint32_t lastUpdate = 0L;
uint32_t lastSync = 0L;
void display() {
    int secondsLeft;
    switch (mode) {
        case 0: break; // noop
        case 1:
            tube.show(
                hour(localTime),
                minute(localTime),
                second(localTime)
            );
            break;
        case 2:
            displayNumber(frameRate);
            break;
        case 3: // Mode 3 = timer running
            if (NULL == timerStart) {
                timerStart = localTime;
            }
            secondsLeft = (timerStart + timer) - localTime;

            if (secondsLeft <= 0) {
                // @TODO: Flash the zeroes for a few seconds
                mode = 1;
                timerStart = NULL;
            }

            tube.show(
                secondsLeft / 60 % 60,
                secondsLeft % 60,
                (millis() - resetMillis) / 10
            );
            break;
        case 4: // Disable tubes ready for code push
            tube.show(-1,-1,-1);
            mode = 0;
            break;
        case 5:
            if (!inSync) {
                displayNumber(lastUpdate + 10000L - millis());
            } else {
                displayNumber(lastSync + 3600000L - millis());
            }
            break;
        case 6:
            displayNumber(millis());
            break;

    }
}

// Time sync callback function
void syncTime(uint32_t time)
{
    // Set it into hardware clock
    setTime(time);
    inSync = true;
    //lastSync = millis(); //@TODO: Figure out why this isn't needed
}

void displayNumber(unsigned long number) {
    int t1 = number % 100;
    int t2 = number / 100 % 100;
    int t3 = number / 10000 % 100;
    tube.show(t3, t2, t1);
}

void setup() {
    // Go through a POST sequence
    tube.show(-1,-1,-1);
    delay(1000);
    tube.degauss(1);
    tube.show(-1,-1,-1);
    delay(1000);
    tube.show(-1,-1,0);
    ntpClient.setNtpCallback(syncTime);
    uint16_t port = 8000;
    ntpClient.udpListen(udpListen, port);
    tube.show(-1,-1,1);
    int result = ntpClient.init();
    tube.show(-1,-1,2);
}

time_t prevDisplay = 0; // when the digital clock was displayed


unsigned int updates = 0;
void loop() {
    while (1) {
        ntpClient.processNtpPacket();

        // Schedule NTP update
        // 3600000L
        if (lastSync + 3600000L < millis() ) {
            inSync = false;
        }

        // If update is required, try it
        if(!inSync && lastUpdate + 10000L < millis() ) {
            lastUpdate = millis();
            ntpClient.update();
            continue;
        }

        // Calculate the local time every second
        if (now() != prevDisplay) {
            prevDisplay = now();
            frameRate = updates;
            updates = 0;

            // See how many millis we have
            millisPerSecond = millis() - resetMillis;
            resetMillis = millis();

            localTime = UK.toLocal(now(), &tcr);
        }
        display();
        updates++;
    }
}

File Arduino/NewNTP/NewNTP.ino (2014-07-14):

#include "Tube.h"
#include <EtherCard.h>
#include <Time.h>

static uint8_t mymac[6] = { 0x54,0x55,0x58,0x10,0x00,0x25};

// IP and netmask allocated by DHCP
static uint8_t myip[4] = { 192,168,1,78 };
static uint8_t mynetmask[4] = { 255,255,255,0 };
static uint8_t gwip[4] = { 192,168,1,254 };
static uint8_t dnsip[4] = { 192,168,1,254 };
static uint8_t dhcpsvrip[4] = { 192,168,1,254 };
//static uint8_t ntpip[4] = { 91,189,94,4 };
static uint8_t ntpip[4] = { 192,168,1,25 };

// Packet buffer, must be big enough to packet and payload
#define BUFFER_SIZE 550
byte Ethernet::buffer[BUFFER_SIZE];
uint8_t clientPort = 123;

uint32_t timeLong;

void setupNtp() {
  Serial.println( F("EtherCard/Nanode NTP Client" ) );

  uint8_t rev = ether.begin(sizeof Ethernet::buffer, mymac);
  Serial.print( F("\nENC28J60 Revision ") );
  Serial.println( rev, DEC );
  if ( rev == 0) 
    Serial.println( F( "Failed to access Ethernet controller" ) );

  //Serial.println( F( "Setting up DHCP" ));
  //if (!ether.dhcpSetup())
  //  Serial.println( F( "DHCP failed" ));
  ether.staticSetup(myip, gwip);
 while (ether.clientWaitingGw())
    ether.packetLoop(ether.packetReceive());
  Serial.println("Gateway found");

  ether.printIp("My IP: ", ether.myip);
  //ether.printIp("Netmask: ", ether.mymask);
  ether.printIp("GW IP: ", ether.gwip);
  ether.printIp("DNS IP: ", ether.dnsip);
}
void sendNtpRequest() {
  //if (!ether.dnsLookup("ntp2d.mcc.ac.uk")) {
  //  Serial.println( F("DNS failed" ));
  //} else {
  //  ether.printIp("SRV: ", ether.hisip);
    ether.ntpRequest(ntpip, ++clientPort);
  //}
}

uint32_t receiveNtpPacket() {
  uint16_t dat_p;
  int plen = 0;
  
  // Main processing loop now we have our addresses
    // handle ping and wait for a tcp packet
    plen = ether.packetReceive();
    dat_p=ether.packetLoop(plen);
    // Has unprocessed packet response
    if (plen > 0) {
      if (ether.ntpProcessAnswer(&timeLong,clientPort)) {
        Serial.print( F( "Time:" ));
        Serial.println(timeLong); // secs since year 1900
        return timeLong;
      }
    }
    return 0;
}


// Time stuff
time_t prevDisplay = 0; // when the digital clock was displayed
const  long timeZoneOffset = -3600L; // set this to the offset in seconds to your local time;

void setupTime() {
  Serial.println("waiting for sync");
  setSyncProvider(getNtpTime);
  setSyncInterval(5); // Set seconds between re-sync (5s for test only)
  while(timeStatus()== timeNotSet)   
     ; // wait until the time is set by the sync provider
}

unsigned long getNtpTime()
{
  const unsigned long seventy_years = 2208988800UL + timeZoneOffset;
  uint32_t nowTime;
  sendNtpRequest();

  do{
    nowTime = receiveNtpPacket();

  } while(nowTime == 0);

  return (long)nowTime - seventy_years;
}
void digitalClockDisplay(){
  // digital clock display of the time
  Serial.print(hour());
  printDigits(minute());
  printDigits(second());
  Serial.print(" ");
  Serial.print(day());
  Serial.print(" ");
  Serial.print(month());
  Serial.print(" ");
  Serial.print(year()); 
  Serial.println(); 
}

void printDigits(int digits){
  // utility function for digital clock display: prints preceding colon and leading 0
  Serial.print(":");
  if(digits < 10)
    Serial.print('0');
  Serial.print(digits);
}
void loopTime() {
  if( now() != prevDisplay) //update the display only if the time has changed
  {
    prevDisplay = now();
    digitalClockDisplay();  
  }
}

uint32_t lastUpdate = 0;
void setup(){
  Serial.begin(19200);
  delay(5000);
  setupNtp();
  setupTime();
  lastUpdate = millis();
  Serial.println("Done");
}

void loop(){
  receiveNtpPacket();
  loopTime();
    //if( lastUpdate + 2000L < millis() ) {
      //lastUpdate = millis();
      //sendNtpRequest();
    //}
}

// End

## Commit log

2014-07-07 Add Eagle board files
    [Power_board.brd, Power_board.sch, Tube_board_2tubes.brd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]
2014-07-14 Implemented NTP and refactored Tube logic into its own class
2014-07-23 Tweaked Software
    Swapped tube pins for easier PCB routing. Uncommented bunch of debug
    stuff
    [Tube.cpp, TubeClock.ino]
2014-07-23 Correct Tube pins, and comment out Ethernet init
    [TubeClock.ino]
2014-07-28 Add USBTintISP board
    Also cleaned up some old pcb designs
    [Tube_board_v3_print.brd, driver_board_v1.brd, driver_board_v1.sch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]
2014-10-30 Added steps to work with Arduino Micro as ISP
2014-10-30 WIP
    A bunch of changes to bring it back into operation. Note that the
    Ethernet Chip pin is 10.
2014-11-07 Add a UDP interface to turn off the tubes
    This should help with uploading code without manually disabling the tubes
2014-11-08 Disable tubes on UDP access
2014-12-26 Implement JSON stuff + frame rate
2014-12-27 Implement timer mode
